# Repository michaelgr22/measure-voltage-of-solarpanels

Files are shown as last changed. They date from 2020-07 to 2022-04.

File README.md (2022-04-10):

# Analyzing the behavior of solar cells
Solar cells have roughly the same behavior as photodiodes. The internal resistance depends on the exposed light.
To analyze the internal resistance, we measure the voltage on a known resistor and the opencircuit voltage. Illuminance is also measured to associate it with the internal resistance.

opencircuit voltage

resistor voltage

The measurements are fully automated to provide accurate data at any time.

## How it works:




## Some Diagramms created with the collected data:

*current-voltage curve:*


The graph shows clearly a curve like a diode.

*open circuit voltage - illuminance*


As you can see the open-circuit-voltage of a solar cell changes with the natural logarithm of the irradiance.

## App to track live data:
https://github.com/michaelgr22/solar_measurement_app

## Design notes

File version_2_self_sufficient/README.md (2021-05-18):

## **Measure Voltage of Solarpanels self sufficient**

### Requirements:
Hardware:  

    1x ESP32 NodeMCU 
    1x Panasonic NCR18650B (Li-Ion 3.7 V 3400 mAh) 
    1x MCP1700 3.3 V regulator 
    1x TP4056 
    8x Solar Panels (1,5 V)   
    1x Capacitor (100 microfarads) 
    1x Resistor (220 Ohms)
    1x BH1750 Light Sensor

Software:  

    1x Webserver  
    1x PostgresDB  

-------
### Wiring: 
  


------

### How it works:

 *electronics:*

    - 2 panels for measuring open circuit voltage, 2 panels for measuring resistor voltage -> internal resistance can be calculated
    - BH1750 to measure light in lux
    - 4 panels to operate the NodeMCU, excess energy can be stored in the battery
    - 3.3 V regulator to reduce the voltage comming from the TP4056
    - capacitor to smooth the voltage for 3.3 V Input of NodeMCU

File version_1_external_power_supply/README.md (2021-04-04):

## **Measure Voltage of Solarpanels with external power supply**

### Requirements:
Hardware:  

    1x Arduino Uno  
    1x ESP8266-01S  
    1x Voltage Sensor  
    1x DS3231  
    3x Solar Panels (1,5 V)  
    1x External Power Supply (3,3 V) 

Software:  

    1x Webserver  
    1x PostgresDB  

-------
### Wiring: 
  


------

### How it works:

    1. Arduino collects the data (collect_data_on_arduino.ino)  
    	Voltage from voltage sensor  
    	Current time from DS3231  
    2. Arduino sends the data via SoftwareSerial to ESP8266 (collect_data_on_arduino.ino)  
    3. ESP8266 formats the data and sends it via POST request to webserver (esp8266-push_data_to_webserver.ino)  
    4. Webserver  inserts data into Postgres database (insert-data-in-postgres.php)  
    5. Now you can run different queries on the data e.g. with pgAdmin  



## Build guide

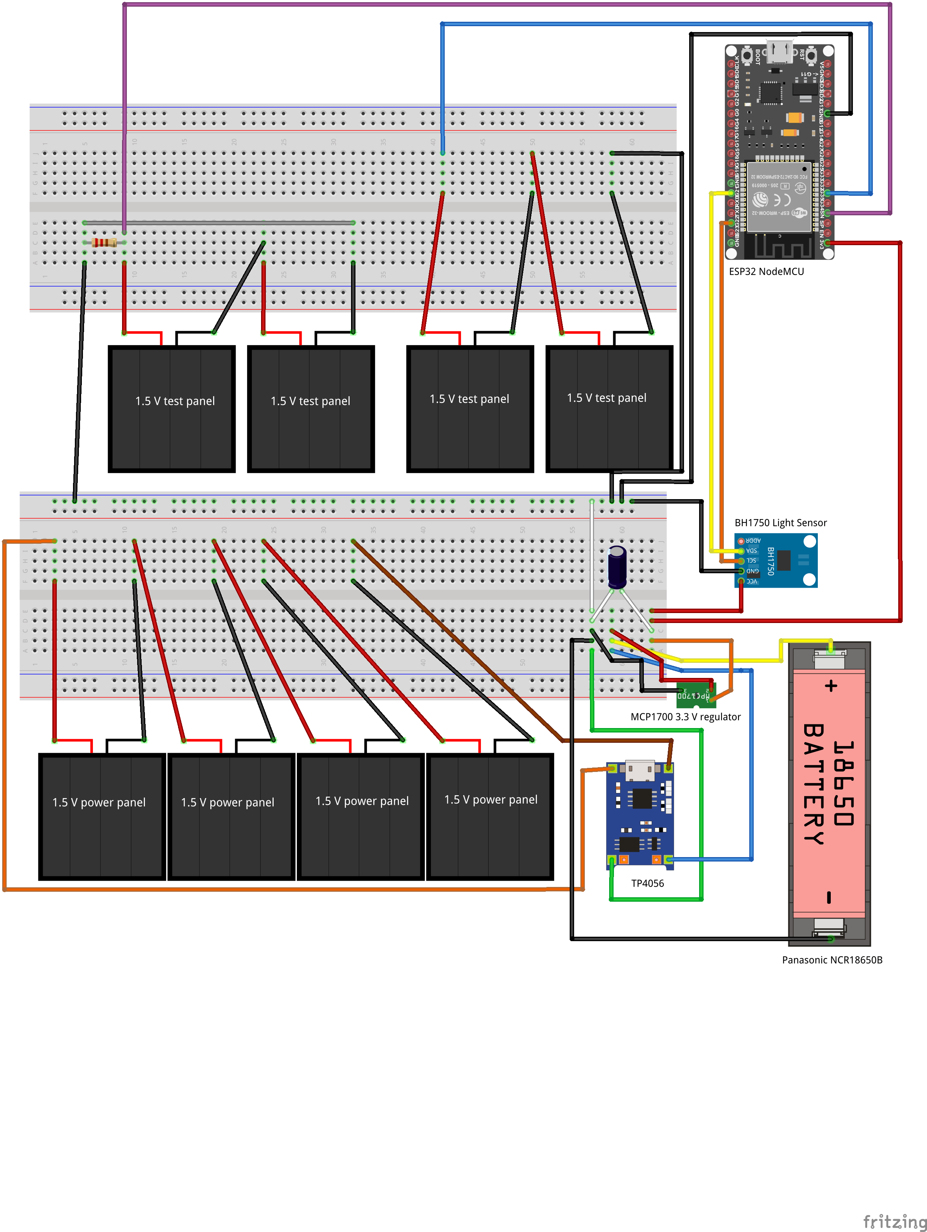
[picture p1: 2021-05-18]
version_2_self_sufficient/wiring/v2_fritzing_bb.png

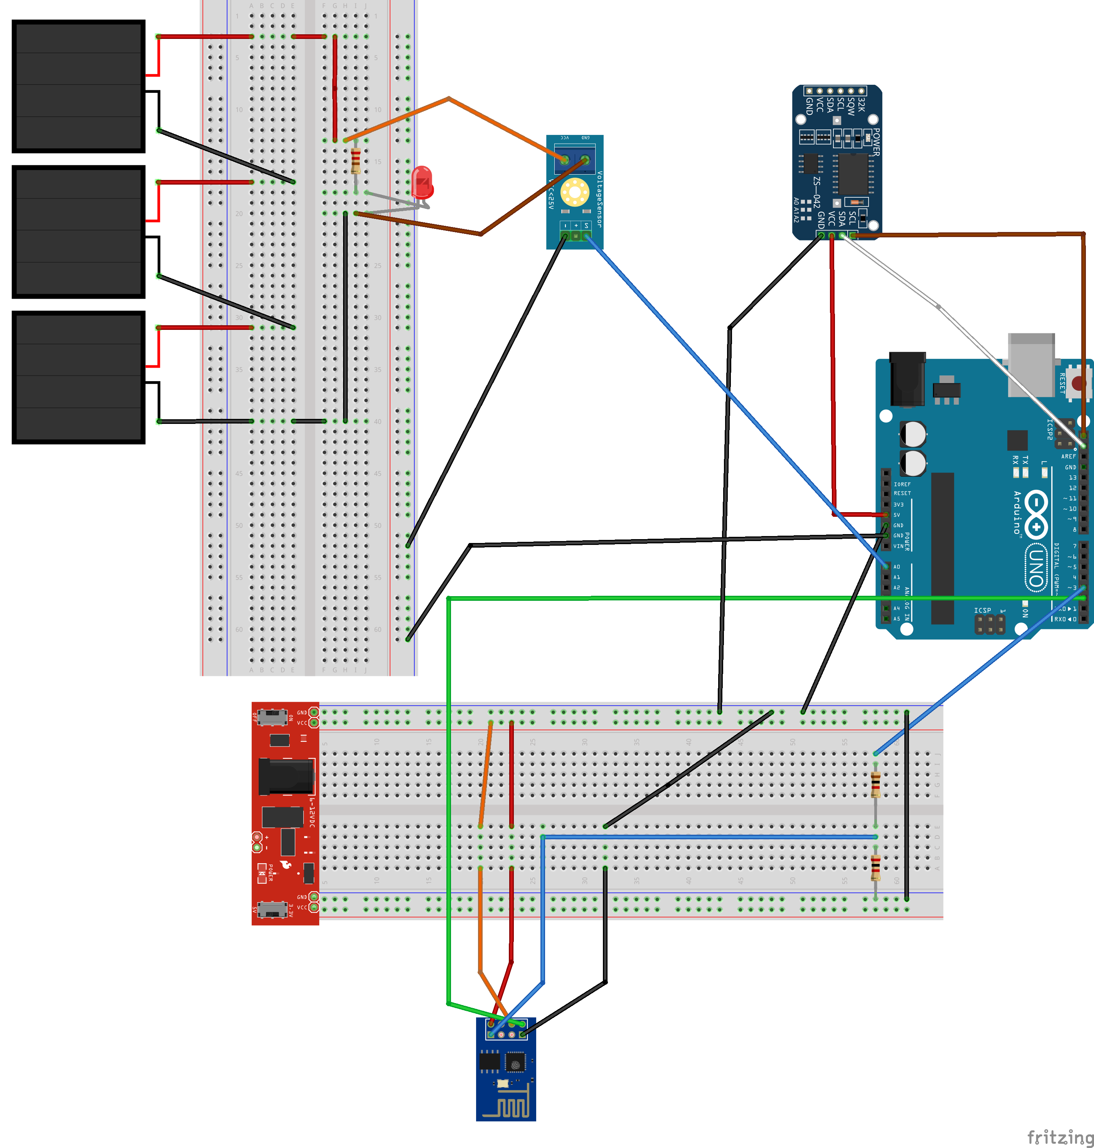
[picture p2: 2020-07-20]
version_1_external_power_supply/wiring/wiring_bb.png

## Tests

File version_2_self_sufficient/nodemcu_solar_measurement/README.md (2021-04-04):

Compatible with VSCode and PlatformIO Plugin.

[PlatformIO](https://github.com/platformio/vscode-platformio/blob/master/README.md)

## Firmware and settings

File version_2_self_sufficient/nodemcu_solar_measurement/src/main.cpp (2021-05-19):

#include <Arduino.h>
#include <HTTPClient.h>
#include <BH1750.h>
#include <Wire.h>
#include <esp_adc_cal.h>
#include <esp_bt_main.h>
#include <esp_bt.h>
#include <esp_wifi.h>
#include <esp_sleep.h>
#include <string.h>
#include "time.h"
#include ".wificredentials.cpp"

const int pin_resistor_voltage = 39;
const int pin_opencircuit_voltage = 35;
const int pin_sda = 21;
const int pin_scl = 22;

bool connectToWifi()
{
  WifiCredentials wificredentials;

  WiFi.begin(wificredentials.ssid, wificredentials.password);

  int wificounter = 0;
  while (WiFi.status() != WL_CONNECTED && wificounter < 10)
  {
    delay(500);
    Serial.print(".");
    wificounter++;
  }

  Serial.println("Connected to Wifi");

  return WiFi.isConnected();
}

void enterSleepMode()
{
  WiFi.disconnect(true);
  delay(300);

  esp_bluedroid_disable();
  esp_bt_controller_disable();
  esp_wifi_stop();

  uint64_t sleeptime = 900000000; //900000000 microseconds = 15 minutes
  //uint64_t sleeptime = 120000000; //120000000 microseconds = 2 minutes
  //sleeptime = 13500000000; 13500000000 microseconds = 3,75 h

  esp_sleep_enable_timer_wakeup(sleeptime);
  esp_light_sleep_start();
}

float getIlluminance()
{
  BH1750 lightmeter;

  lightmeter.begin(BH1750::ONE_TIME_HIGH_RES_MODE);

  int counter = 0;
  while (!lightmeter.measurementReady(true) && counter < 10)
  {
    delay(100);
    counter++;
  }
  return lightmeter.readLightLevel();
}

float getVoltage(const int pin)
{
  const int ref_voltage = 1135;
  adc1_channel_t channelnum;

  switch (pin)
  {
  case (39):
    channelnum = ADC1_CHANNEL_3;
    break;

  case (34):
    channelnum = ADC1_CHANNEL_6;
    break;

  case (35):
    channelnum = ADC1_CHANNEL_7;
    break;

  case (32):
    channelnum = ADC1_CHANNEL_4;
    break;
  }

  esp_adc_cal_characteristics_t *adc_chars = new esp_adc_cal_characteristics_t;

  analogReadResolution(11);
  esp_adc_cal_characterize(ADC_UNIT_1, ADC_ATTEN_DB_11, ADC_WIDTH_BIT_11, ref_voltage, adc_chars);
  adc1_config_channel_atten(channelnum, ADC_ATTEN_DB_11);

  int voltage_mv = esp_adc_cal_raw_to_voltage(analogRead(pin), adc_chars);

  return voltage_mv / 1000.0;
}

void sendPostRequest(const float resistor_voltage, const float opencircuit_voltage, const float illuminance)
{
  const char *servername = "http://kuberneteshome:30830/sendvoltage-to-postgres.php";
  HTTPClient http;

  http.begin(servername);
  http.addHeader("Content-Type", "application/x-www-form-urlencoded");
  String httprequestdata = "resistorvoltage=" + String(resistor_voltage, 3) + "&opencircuitvoltage=" + String(opencircuit_voltage, 3) + "&illuminancelux=" + String(illuminance);

  int status_code = 0;
  int postrequest_tries = 0;
  while (status_code != 200 && postrequest_tries < 10)
  {
    status_code = http.POST(httprequestdata);
    postrequest_tries++;
  }
}

void setup()
{
  Serial.begin(115200);
  Serial.println("Start");
  Wire.begin(pin_sda, pin_scl); //for BH1750
}

void loop()
{
  if (connectToWifi())
  {
    sendPostRequest(getVoltage(pin_resistor_voltage), getVoltage(pin_opencircuit_voltage), getIlluminance());
  }
  enterSleepMode();
}

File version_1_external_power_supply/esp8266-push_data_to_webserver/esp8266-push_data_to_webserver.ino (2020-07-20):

#include <stdio.h>
#include <string.h>
#include <ESP8266WiFi.h>
#include <ESP8266HTTPClient.h>
#include <WiFiClient.h>

void setup() {
 Serial.begin(9600);
 ConnectToNetwork();
 delay(5000);
}

void loop() {
  char data[30] = "";
  size_t sizedata = sizeof(data)/sizeof(data[0]);
  ReadRecievedData(data, sizedata);
  
  if ((data != NULL) && (data[0] != '\0')) {
    SendPostRequest(data);
    delay(50000);  
  }  
}

void ConnectToNetwork(){

  const char* ssid     = "***";
  const char* password = "***";

  WiFi.begin(ssid, password);
  Serial.println("Connecting");
  while(WiFi.status() != WL_CONNECTED) { 
    delay(500);
    Serial.print(".");
  }
  Serial.println("");
  Serial.print("Connected to WiFi network with IP Address: ");
  Serial.println(WiFi.localIP());
}

void ReadRecievedData(char* data, size_t sizedata){
  String incomingdata="";
  boolean StringReady = false;

  while (Serial.available()){
    incomingdata=Serial.readString();
    incomingdata.toCharArray(data, sizedata);
    StringReady=true;
  }
  Serial.println(data);
}

void SendPostRequest(char* data){
  const char* serverName = "http://<ip>:31630/write-post-to-postgres.php";

  //Copy String because strtok needs more space
  char cdata[50] = "";
  strncpy(cdata, data, strlen(data));
  
  char* voltage = strtok(cdata, ",");
  char* date = strtok(NULL, ",");

  char datepost[22];
  size_t sizedatepost = sizeof(datepost)/sizeof(datepost[0]);
  ModifyDateForPost(date, datepost, sizedatepost);
  
  String voltageS = String(voltage);
  String datepostS = String(datepost);

  Serial.println("voltage " + voltageS);
  Serial.println("date " + datepostS);

  //Check WiFi connection status
  if(WiFi.status()== WL_CONNECTED){
    HTTPClient http;

    // Your Domain name with URL path or IP address with path
    http.begin(serverName);
    
    // Specify content-type header
    http.addHeader("Content-Type", "application/x-www-form-urlencoded");
       
    // Prepare your HTTP POST request data
    String httpRequestData = "voltage=" + voltageS + "&measure_time=" + datepostS;

    // Send HTTP POST request
    int httpResponseCode = http.POST(httpRequestData);

    if (httpResponseCode>0) {
      Serial.print("HTTP Response code: ");
      Serial.println(httpResponseCode);
    }
    else {
      Serial.print("Error code: ");
      Serial.println(httpResponseCode);
    }
    // Free resources
    http.end();
  }
  else {
    Serial.println("WiFi Disconnected");
  }
}

void ModifyDateForPost(char* date, char* datepost, size_t sizedatepost){
  strncpy(datepost, date, strlen(date));
  int pos = 10; //Position of whitespace
  char toInsert[4] = "%20";
  
  //shift elements forward
  for (int i = sizedatepost; i >= pos; i--){
    datepost[i] = datepost[i-2];
  }

  for (int i = 0; i < strlen(toInsert); i++){
    datepost[pos+i] = toInsert[i];
  }
  datepost[sizedatepost-1] = '\0';
}

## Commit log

2020-07-20 added script for arduino to read voltage and current time and send them over software serial
2020-07-20 added wiring files
    [wiring.fzz]
2021-04-04 created new structure because of second version
    [wiring.fzz]
2021-04-04 removed comments and fixed sending problem
    [main.cpp]
2021-04-04 added wiring for v2
    [v2_fritzing.fzz]
2021-04-17 implemented BH1750 sensor for measuring lux
2021-05-04 interrupted endless loop when wifi disconnects
2021-05-18 added light sensor to fritzing and readme
    [v2_fritzing.fzz]
2021-05-18 added php script for inserting data
